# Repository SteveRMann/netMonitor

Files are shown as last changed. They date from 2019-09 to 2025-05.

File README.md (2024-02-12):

# net_monitor
Sketch to monitor the status of my router, internet connection and local servers.
----
My Smart Home has grown into a Frankenstein monster.

I started with Node-Red and Mosquitto MQTT broker on a single Raspberry Pi3.  At some point I wanted to add some Z-Wave
devices and someone on the Node-Red forums told me that my best route was to install Home Assistant and an Aeotec Z-Stick,
then I could control the Z-Wave devices from Node-red.  I didn't want to risk messing up my currently running Pi with
Node-red and Mosquitto, so I installed Home Assistant on a second Raspberry Pi.  I discovered that I like Home Assistant
and instead of growing my system on Node-Red, as originally planned, I spent the next months adding more devices to Home Assistant.

So now I had two Raspberry Pis running my smart home.  Then came the Tradfri lights, so add the Tradfri Gateway to the mix.
Next, I added some IP cameras.

So when my wife says that "Alexa isn't listening to me!", I have a number of places to look for the problem.
(Since I am always doing something to my stuff, I am always breaking something).

My troubleshooting process involves pinging all the likely suspects to make sure they are all online.  I wanted a faster and
easier way to determine where to start looking for a problem.  Thus was born my Net Monitor Applpiance project.

The Net Monitor Appliance just pings the IP address of the critical devices on my network, and if a good ping is found,
lights a green LED.  If a ping is not responsive, a red LED lights.  The loop repeats every 30-seconds.  So, if I look up
and see a "green board", then I know not to take the time to ping up to 10 devices.

I chose to make the Net Monitor on the NodeMCU platform because it has WiFi and works from any 5V micro-USB wall wart.
I could have easily included an LCD display, but I just wanted to have something to determine at a glance if I have a net problem.

## To Do
Check out a different esp8266ping.h library
https://github.com/dancol90/ESP8266Ping/blob/master/examples/SimplePing/SimplePing.ino

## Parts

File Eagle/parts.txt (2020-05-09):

Partlist

Exported from net_monitor.brd at 5/9/2020 10:39 AM

EAGLE Version 9.3.2 Copyright (c) 1988-2019 Autodesk, Inc.

Assembly variant: 

Part     Value          Package       Library     Position (inch)       Orientation

IC1      MCP23008/P     DIL18         adafruit    (1.3 1.05)            R90
LED1     RGBLED_CC      LED5MMRGB     myParts     (0.85 1.5)            R0
LED2     RGBLED_CC      LED5MMRGB     myParts     (0.85 1.15)           R0
LED3     RGBLED_CC      LED5MMRGB     myParts     (0.85 0.8)            R0
LED4     RGBLED_CC      LED5MMRGB     myParts     (0.85 0.45)           R0
R1       5K1            0207/10       adafruit    (0.4 1.6)             R0
R2       1K             0207/10       adafruit    (0.4 1.45)            R0
R3       5K1            0207/10       adafruit    (0.4 1.25)            R0
R4       1K             0207/10       adafruit    (0.4 1.1)             R0
R5       5K1            0207/10       adafruit    (0.4 0.9)             R0
R6       1K             0207/10       adafruit    (0.4 0.75)            R0
R7       5K1            0207/10       adafruit    (0.4 0.55)            R0
R8       1K             0207/10       adafruit    (0.4 0.4)             R0
R9       5K1            0207/10       adafruit    (0.4 0.25)            R180
W1       WEMOS-D1-MINI  WEMOS-D1-MINI diy-modules (2.35 1.05)           R90

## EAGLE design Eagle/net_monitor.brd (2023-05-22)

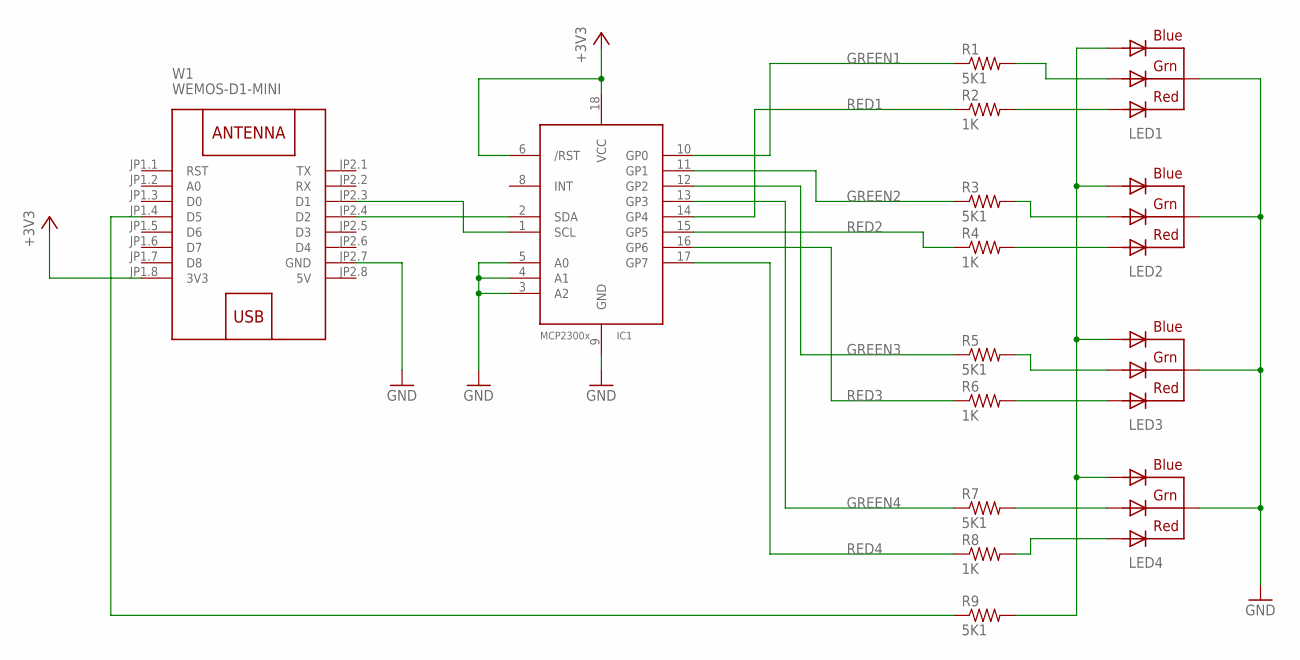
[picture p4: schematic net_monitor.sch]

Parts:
IC1: MCP23008/P; DIL18
LED1, LED2, LED3, LED4: RGBLED_CC; LED5MMRGB
R1, R3, R5, R7, R9: 5K1; 0207/10; MPN CRCW12065K10FKEA
R2, R4, R6, R8: 1K; 0207/10
W1: WEMOS-D1-MINI

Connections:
5V: W1.JP2.8 (5V)
+3V3: IC1.6 (/RST), IC1.18 (VCC), W1.JP1.8 (3V3)
GND: IC1.3 (A2), IC1.4 (A1), IC1.5 (A0), IC1.9 (GND), LED1.2 (CATHODE), LED2.2 (CATHODE), LED3.2 (CATHODE), LED4.2 (CATHODE), W1.JP2.7 (GND)
GREEN1: IC1.10 (GP0), R1.1
GREEN2: IC1.11 (GP1), R3.1
GREEN3: IC1.12 (GP2), R5.1
GREEN4: IC1.13 (GP3), R7.1
unnamed: LED4.3 (GREEN), R7.2
unnamed: LED1.3 (GREEN), R1.2
unnamed: LED1.4 (BLUE), LED2.4 (BLUE), LED3.4 (BLUE), LED4.4 (BLUE), R9.2
unnamed: LED1.1 (RED), R2.2
unnamed: LED3.3 (GREEN), R5.2
unnamed: LED3.1 (RED), R6.2
unnamed: LED2.3 (GREEN), R3.2
unnamed: LED2.1 (RED), R4.2
unnamed: IC1.1 (SCL), W1.JP2.3 (D1)
unnamed: LED4.1 (RED), R8.2
unnamed: R9.1, W1.JP1.4 (D5)
unnamed: IC1.2 (SDA), W1.JP2.4 (D2)
RED1: IC1.14 (GP4), R2.1
RED2: IC1.15 (GP5), R4.1
RED3: IC1.16 (GP6), R6.1
RED4: IC1.17 (GP7), R8.1

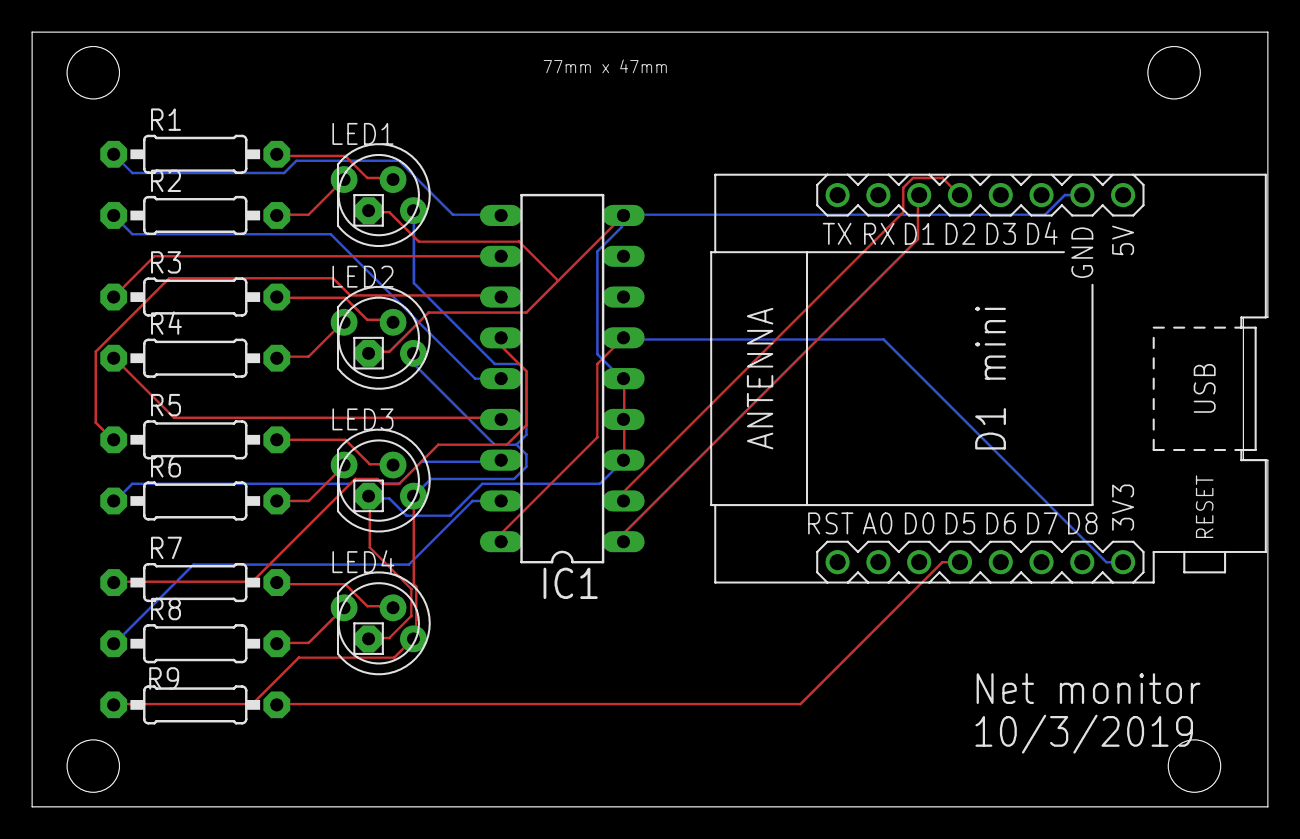
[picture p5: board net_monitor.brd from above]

Board: 2 copper layers, 77.0 x 48.2 mm, 15 parts (0 on the bottom side), 22 nets.

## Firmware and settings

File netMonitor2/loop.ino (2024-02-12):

//************************************** LOOP *******************************
void loop() {
  if (aTimer.ding()) {                          //If the timer has expired..
    ipscan();                                   //Ping the three local IP addresses
    aTimer.start();                             //Restart the timer.
  }
}


void ipscan() {
  for (int ipNum = 0; ipNum < ipCount; ipNum++) {
    yellow(ipNum);
    wSend(myBits);
    yield();                                    //Reset the WDT on the ESP8266

    Serial.print(F("Pinging.. "));
    Serial.print(ipAddressArray[ipNum]);
    if (Ping.ping(ipAddressArray[ipNum],10)) {
      Serial.println(F(" OK"));
      bitWrite(myBits, ipNum, 1);               //Turn on the green LED
      bitWrite(myBits, ipNum + 4, 0);           //Turn off the red LED
      wSend(myBits);

    } else {
      Serial.println(F(" FAIL"));
      bitWrite(myBits, ipNum, 0);             // Turn off the green LED
      bitWrite(myBits, ipNum + 4, 1);         // Turn on the red LED
      wSend(myBits);

      Serial.println();
      Serial.print(F("Error: "));
      Serial.println(ipAddressArray[ipNum]);
      Serial.println();
    }

  }
}

void hostscan() {
  //For each host in the list
  for (int hostNum = 0; hostNum < numberOfHosts; hostNum++) {
    Serial.print(F("Pinging host["));
    Serial.print(hostNum);
    Serial.print(F("]= "));
    Serial.println(hosts[hostNum]);
    Serial.print(F("Pinging "));
    Serial.println(hosts[hostNum]);
    Serial.println((Ping.ping(hosts[hostNum])) ? "OK" : "fail");
  }
}

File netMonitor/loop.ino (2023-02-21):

//************************************** LOOP *******************************
void loop() {
  ArduinoOTA.handle();
  if (aTimer.ding()) {                          // If the timer has expired..
    // Serial.println(F("aTimer ding"));
    ipscan();
  }
}


void ipscan() {
  char pingIP[20];                            // IP that we're going to ping.

  //For each IP in the list
  for (int i = 0; i < 4; i++) {               // for four LEDS
    ledNum = i;

    if (i == 3) i = i + random(0, webIpCount);  // Last LED. Select an external IP at random.
    strcpy(pingIP, ipx[i]);

/*
    Serial.println();
    Serial.print(F("IP "));
    Serial.print(i);
    Serial.print(F(",  Led "));
    Serial.println(ledNum);

    Serial.print("Pinging ");
    Serial.print(pingIP);
*/ 
    greenTicker.attach(0.1, greenTick);         // Start greenTick() while we ping

    yield();                                    // Reset the WDT on the ESP8266

    if (Ping.ping(pingIP)) {                    // Ping
      greenTicker.detach();                     // Stop greenTick()
      bitWrite(myBits, ledNum, 1);             // Turn on the green LED
      bitWrite(myBits, ledNum + 4, 0);         // Turn off the red LED
      wSend(myBits);

    } else {
      // FAIL
      greenTicker.detach();                     // Stop greenTick()
      bitWrite(myBits, ledNum, 0);             // Turn off the green LED
      bitWrite(myBits, ledNum + 4, 1);         // Turn on the red LED
      wSend(myBits);
      pingDelay = 10;                           //Retry immediately

      Serial.println();
      Serial.print(F("Error: "));
      Serial.println(pingIP);
      Serial.print(F("LED bits: "));
      printBinaryByte(myBits);
      Serial.println();
      // if (i == 3) client.publish(statusTopic, pingIP);
      ///client.publish(statusTopic, pingIP);
    }
  }
//  Serial.println();
//  Serial.println(F("----------------------"));
  aTimer.start();                 // Restart the timer.

}

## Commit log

2019-09-05 Version 3.0 9/4/2019 Working with three-color LEDs
2019-10-02 Removed local router from the ping list, added plex server. (If the router is offline, no other pings would work anyway).
    Added Eagle folder to the git
    [net_monitor.brd, net_monitor.sch]
2020-08-25 Added MQQT
    Added MQQT to publish the IP of the failed pings. This is used to make a log file in Node red.
    [WiFi.ino, loop.ino, netMonitor.ino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]
2021-03-11 Version 5.1 3/10/2021 Publish the failing IP.
    [WiFi.ino, loop.ino, netMonitor.ino]
2021-03-12 Added four new and removed two problematic external IPs
    Version 5.2 3/12/2021
    Added four new and removed two problematic external IPs
    [netMonitor.ino]
2021-03-12 Fixed the comments in netMonitor.ino
    [netMonitor.ino]
2021-03-16 Check for MQTT connection with each ping. Log all fails.
    Version 5.3 3/16/2021
    Check for MQTT connection with each ping. Log all fails.
    [loop.ino, netMonitor.ino, setup.ino]
2021-09-11 Fixed a comma error in iplist.h
    [netMonitor.ino]
2023-05-22 Added a notch in the PCB for the USB connector
    [net_monitor.brd, net_monitor.sch]
2025-05-11 Moved schematic to images

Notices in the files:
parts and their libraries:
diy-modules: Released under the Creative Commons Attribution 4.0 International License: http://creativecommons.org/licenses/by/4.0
